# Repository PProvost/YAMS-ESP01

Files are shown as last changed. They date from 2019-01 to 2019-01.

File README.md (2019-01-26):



# YAMS-ESP01
Yet Another Motion Sensor - Uses an ESP01 and a cheap PIR motion sensor, sends activation events via MQTT,
optimized for very low power use. Runs on 3 AA batteries (I use Panasonic Eneloop NiMh cells).

## BOM

* ESP8266-01 Module
* HC-SR501 PIR Motion Detector
* MCP1700-3302E TO92 Voltage Regulator
* Resistors:
  - 220 ohm (x1)
  - 3.3K ohm (x1)
* Capacitors:
  - 1uF ceramic (x2)
  - 100nF ceramic (x1)
* Various pin headers, JST and molex connectors as you see fit
* Battery caddy (aim for > 4V but stay within the limits of the MCP1700-3302E)

## Implementation Notes:

* If you have a Puya-based ESP01 module, you may need to apply this patch to get SPIFFS to write correctly:
  https://github.com/letscontrolit/ESPEasy/blob/mega/patches/puya_v3.patch#L8
* You can force the WifiManager to reset its settings by writing the SPIFFS filesystem with a file called
  `/config.json` with the following contents: `{ "reset_settings": true }`. This file is included in the
  /data directory in this repo.

## Building the circuit

Credits: This circuit used in this design is based on the work described in [Benny de Leeuw's article][1].

IMPORTANT!: This is a 3.3V circuit. The HC-SR501 PIR sensor is 5V, so you either need to maintain two power
voltages or modify the PIR to run on 3.3V.

The circuit is designed to be battery powered, requiring between 3.7V and 6V due to the requirements
of the MCP1700 LDO. This requires some special with your PIR sensor. Most of the cheap ones you will
find expect 5V. See below for more information about modding your PIR sensor for 3V3.

Once I've built a few and ironed out the bugs, I will provide STLs for a case and a link to the PCB
on OSHPark.

Please refer to the schematic PDF and the other files in the schematic/ folder.

### Modding the HC-SR501 PIR Sensor

I wanted to reuse the VCC pin on the PIR sensor to make mounting easier, but also to power the PIR sensor
with the same 3.3VDC the ESP takes. For some of my sensors, I made the following modifications successfully:

* Removed the 3V3 voltage regulator
* Connected the cathode (output) side of the diode to the VOUT pad where the regulator had been connected
* Removed the 1k resistor between the controller IC and the signal pin and shorted the two pads.
* NOTE:This permanently changes the sensor to only take 3.3V, do not power it with 5V after removing the regulator.
  If you don't want to remove the regulator from your sensor, you can still power it with 3.3V following the guide [Modifying Cheap PIR Sensors][3], but you may still need to remove the 1k resistor. I've used this approach too.

## Credits & References

1. [Stable ESP01 Motion Sensor][1]
2. [ESP01 Pin Magic][2]
3. [Modifying Cheap PIR Sensors][3]

## TODO:

* Provide a better HASS discovery message
* Better case design
* Button/switch/jumper to make it stay awake (can help with network debugging; see also the DO_NOT_SLEEP define
  in main.cpp)
* Enable [OTA updating](http://esp8266.github.io/Arduino/versions/2.0.0/doc/ota_updates/ota_updates.html),
* Figure out a reset button so you can reset the configuration without flashing the SPIFFS filesystem
  particularly for updating the config.json file but also maybe the firmware.
* (Optional) front facing LED when motion detected
* (Idea) Photoresistor to prevent triggering unless light levels are low enough

[1]: https://medium.com/@leeuwte/stable-esp01-motion-sensor-for-mqtt-2d81c0b1e317
[2]: http://www.forward.com.au/pfod/ESP8266/GPIOpins/ESP8266_01_pin_magic.html
[3]: https://randomnerdtutorials.com/modifying-cheap-pir-motion-sensor-to-work-at-3-3v/

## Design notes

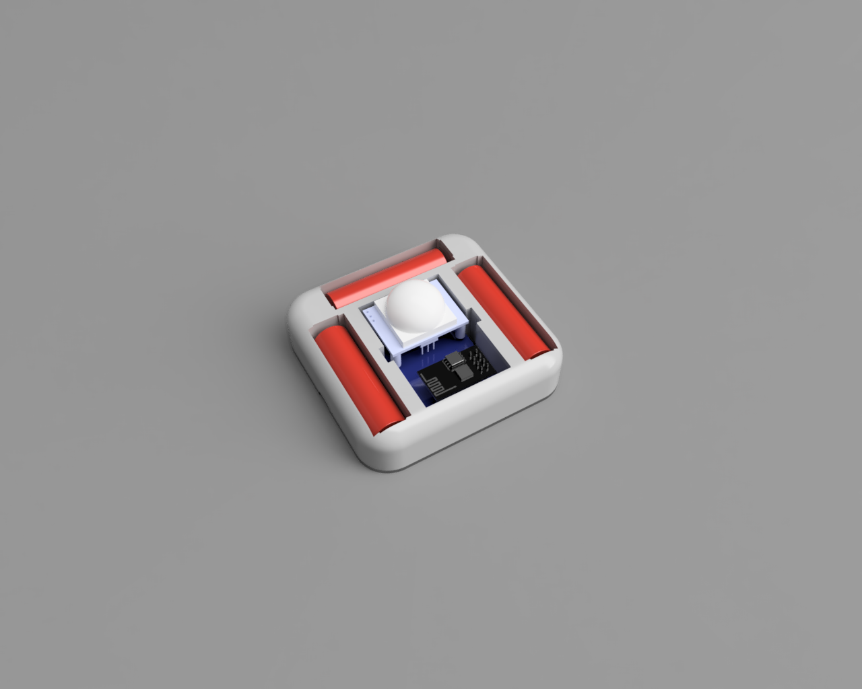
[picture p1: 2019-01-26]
stl/YAMS-Case-New-Everything-Top-Removed.png

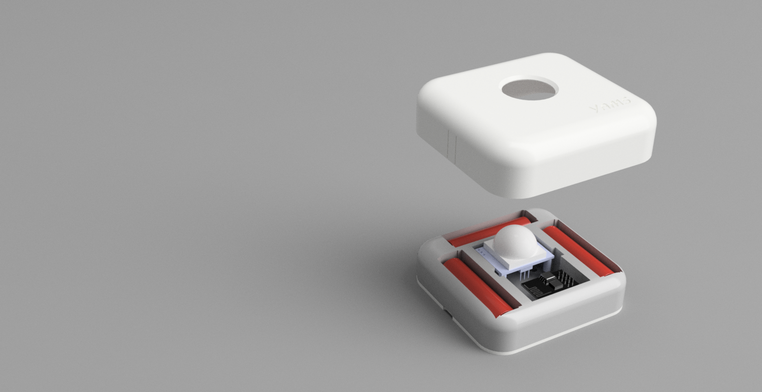
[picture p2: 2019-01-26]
stl/YAMS Round Exploded.png

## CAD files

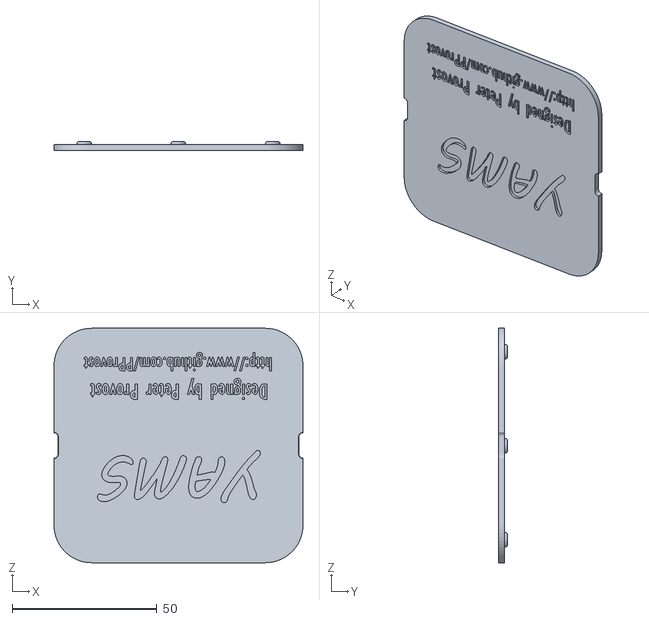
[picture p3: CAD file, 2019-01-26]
stl/Case - Inner Block Bottom Plate.stl
86.0 x 3.00 x 81.0

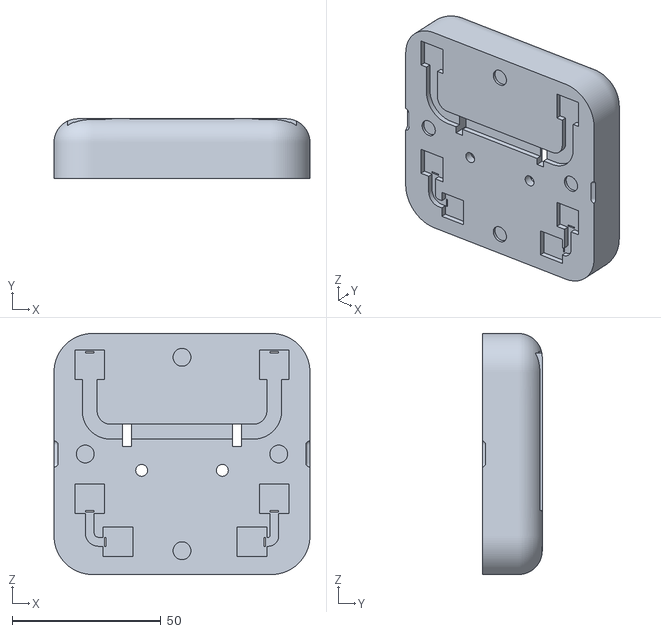
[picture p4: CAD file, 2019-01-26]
stl/Case - Inner Block.stl
86.0 x 20.0 x 81.0

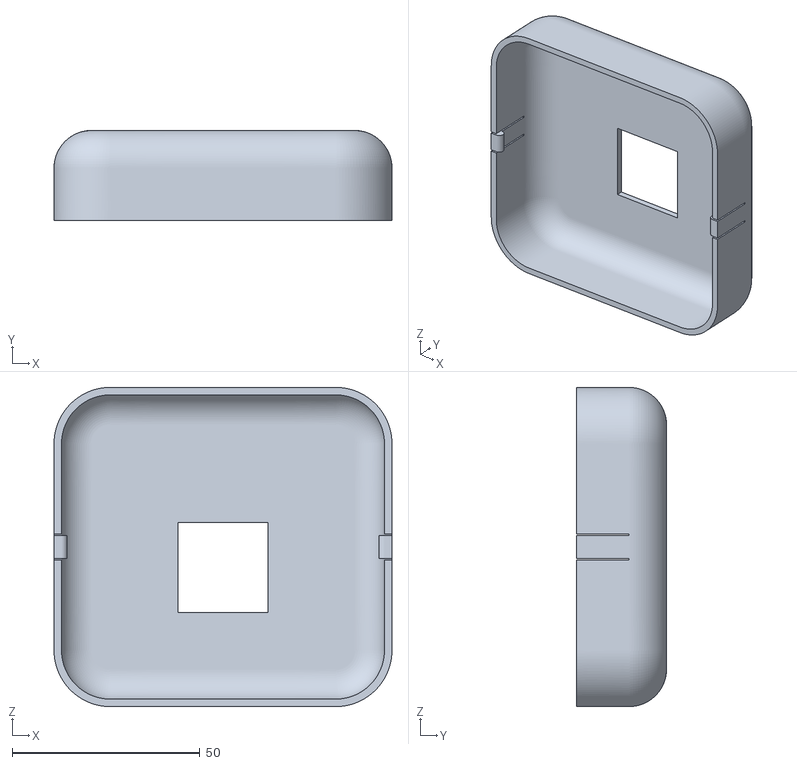
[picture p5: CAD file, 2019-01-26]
stl/Case - Outer Shell.stl
90.0 x 24.0 x 85.0

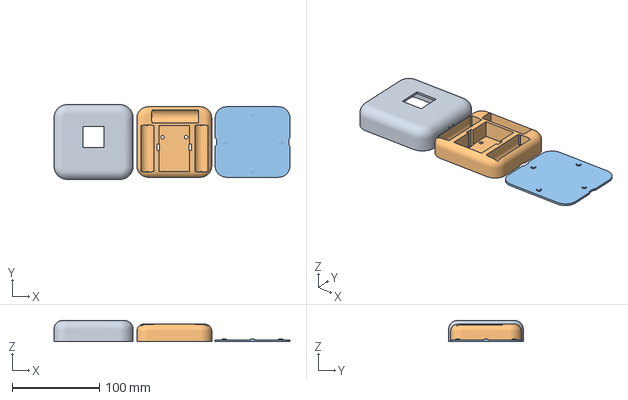
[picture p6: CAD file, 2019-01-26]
stl/YAMS-Case-New-Everything-PLA.curaproject.3mf
271.0 x 85.8 x 24.2 mm

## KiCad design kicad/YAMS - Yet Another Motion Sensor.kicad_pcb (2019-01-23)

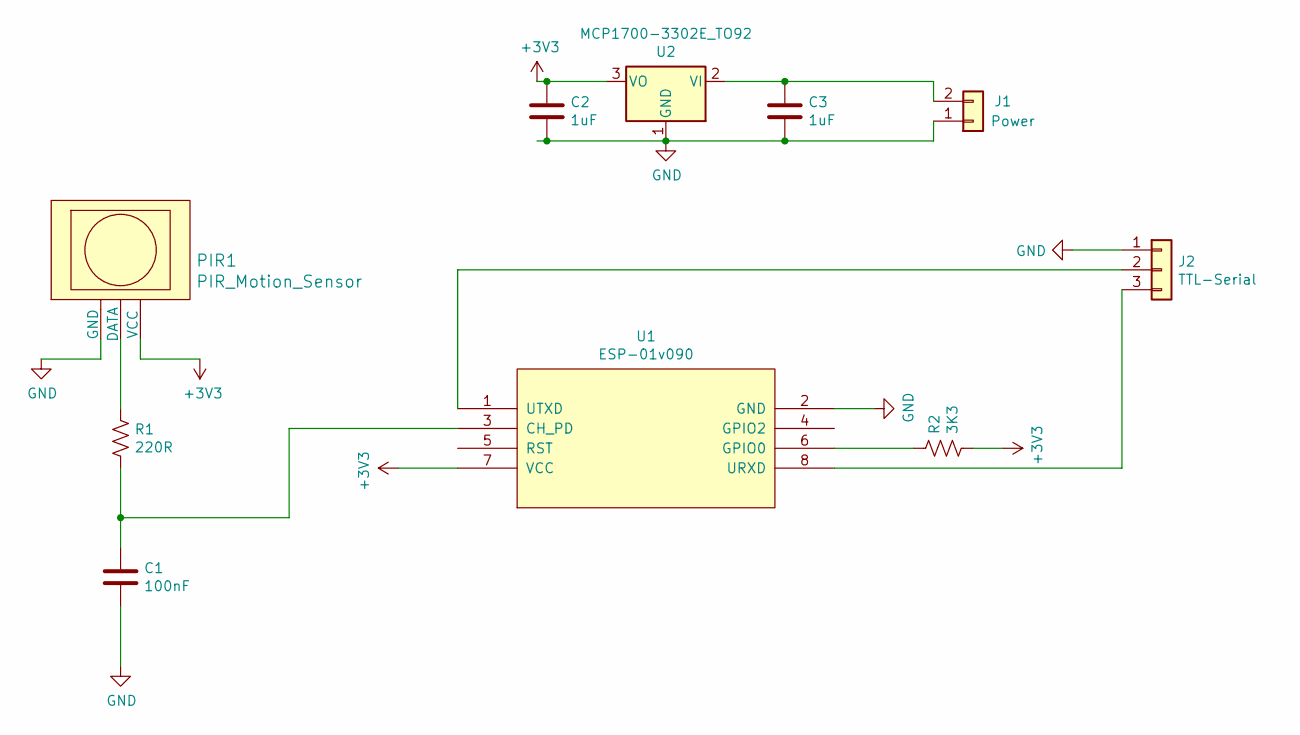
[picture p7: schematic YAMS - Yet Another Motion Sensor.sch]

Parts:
C1: 100nF; C_Disc_D3.8mm_W2.6mm_P2.50mm
C2, C3: 1uF; C_Disc_D3.8mm_W2.6mm_P2.50mm
J1: Power; JST_XH_B02B-XH-A_1x02_P2.50mm_Vertical
J2: TTL-Serial; PinHeader_1x03_P2.54mm_Vertical
PIR1: PIR_Motion_Sensor; PIR_Motion_Sensor_Horiz
R1: 220R; R_Axial_DIN0207_L6.3mm_D2.5mm_P7.62mm_Horizontal
R2: 3K3; R_Axial_DIN0207_L6.3mm_D2.5mm_P7.62mm_Horizontal
U1: ESP-01v090; ESP-01
U2: MCP1700-3302E_TO92; TO-92_Inline

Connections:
+3V3: C2.1, PIR1.3 (VCC), R2.2, U1.7 (VCC), U2.3 (VO)
GND: C1.2, C2.2, C3.2, J1.1, J2.1, PIR1.1 (GND), U1.2 (GND), U2.1 (GND)
unnamed: C1.1, R1.2, U1.3 (CH_PD)
unnamed: C3.1, J1.2, U2.2 (VI)
unnamed: J2.2, U1.1 (UTXD)
unnamed: J2.3, U1.8 (URXD)
unnamed: PIR1.2 (DATA), R1.1
unnamed: R2.1, U1.6 (GPIO0)

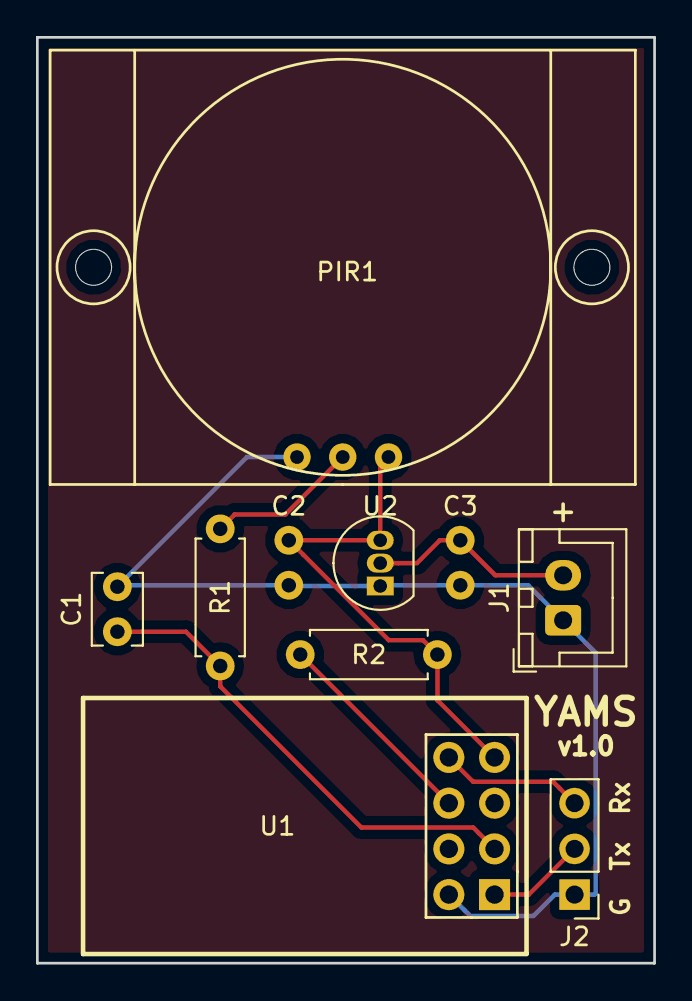
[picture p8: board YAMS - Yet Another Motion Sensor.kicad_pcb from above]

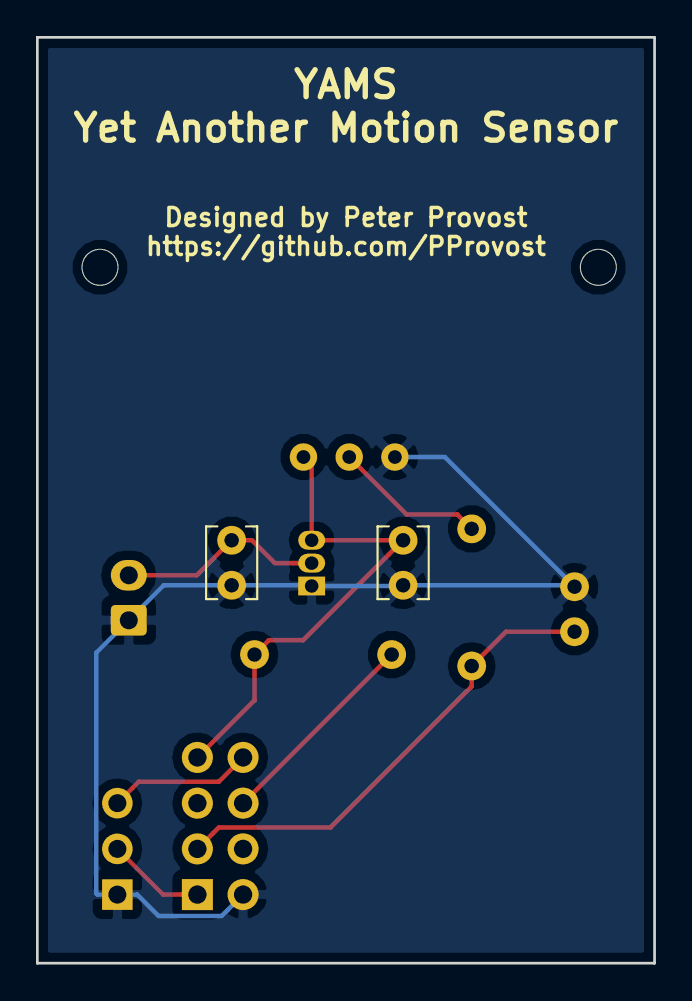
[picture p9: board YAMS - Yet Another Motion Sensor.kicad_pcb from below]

Board: 2 copper layers, 34.3 x 51.4 mm, 10 parts (2 on the bottom side), 8 nets.

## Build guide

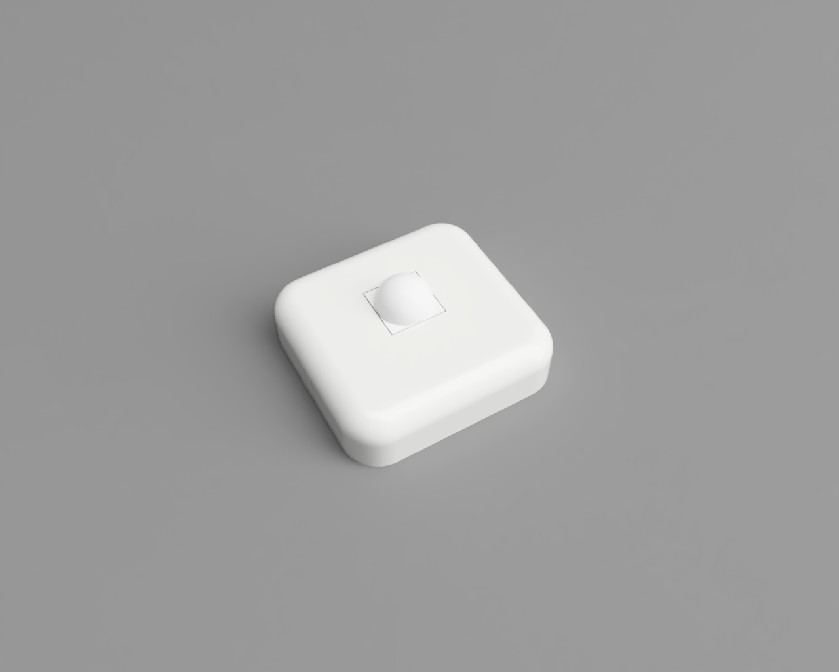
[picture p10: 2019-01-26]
stl/YAMS-Case-New-Everything-Assembled.png

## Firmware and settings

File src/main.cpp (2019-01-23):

#include <Arduino.h>
#include <ESP8266WiFi.h>
#include <PubSubClient.h>

#include "mqttConfig.h"
#include "wifi_helper.h"

// Change this for each device you create
const char *device_host_name = "esp8266-motion-1";

// Change the motion sensor topic as required for your configuration.
// Note that for HASS discovery to work, the structure is expected to be
// <discovery_prefix>/<component>/[<node_id>/]<object_id>
// I'm not using node_id, and the code below will append either "config" 
// (for discovery) or "state" as required.
// See https://www.home-assistant.io/docs/mqtt/discovery/ for more info.
const char *mqtt_topic_template = "esp8266/binary_sensor/DEVICE_HOST_NAME/";

// DEBUGGING: Uncomment to prevent deep sleep at the end of loop() and
// instead just delay for 5s. Useful for debugging or when you need to keep it
// awake. Do not leave this defined or your battery will die in days.
// #define DO_NOT_SLEEP

// This is the number of milliseconds between "on" state and "off" state.
// For simplicity, we do not wait for the PIR to register inactive.
#define INACTIVE_DELAY 2000

PubSubClient client;
MqttConfig config("/config.json");
WifiHelper wifiHelper;
WiFiClient wifiClient;

// Forward declarations
void ensure_mqtt_connected();
void sendHassDiscoveryMessage();

void setup()
{
  Serial.begin(115200);
  // delay(2000); // Make it easier to monitor from the start. Remove when done debugging.
  Serial.println();

  Serial.println("setup() starting");

  config.read();
  wifiHelper.setup_wifi(config);

  Serial.println("Opening MQTT connection...");
  if (!client.connected())
    config.connectMqtt(client, wifiClient);

  sendHassDiscoveryMessage();

  Serial.println("INFO: setup() complete; Wifi and MQTT connected");
}

void loop()
{
  Serial.println("loop(): current config:");
  config.dumpAll(Serial);
  Serial.println();

  String mqttTopic = mqtt_topic_template;
  mqttTopic.replace("DEVICE_HOST_NAME", device_host_name);
  mqttTopic.concat("state");

  // Send on
  Serial.println("- Sending active message");
  client.publish(mqttTopic.c_str(), "ON");
  client.loop();

  // Wait a bit
  delay(INACTIVE_DELAY);

  // Send off
  Serial.println("- Sending inactive message");
  client.publish(mqttTopic.c_str(), "OFF");
  client.loop();

  delay(100);
  Serial.println("Sleeping...");

#ifndef DO_NOT_SLEEP
  ESP.deepSleep(0);
#else
  delay(5000);
#endif
}

void sendHassDiscoveryMessage()
{
  Serial.println("- Sending HASS discovery message");

  String mqttTopic = mqtt_topic_template;
  mqttTopic.replace("DEVICE_HOST_NAME", device_host_name);
  mqttTopic.concat("config");

  String message = "{ \"name\": \"DEVICE_NAME\", \"device_class\": \"motion\" }";
  message.replace("DEVICE_NAME", device_host_name);
  client.publish(mqttTopic.c_str(), message.c_str());
  client.loop();
}

// NOTE: 
// If we want to subscribe to MQTT messages for commands or settings, this is the callback
// void callback(char* topic, byte* payload, unsigned int length) {
//   Serial.print("Message arrived [");
//   Serial.print(topic);
//   Serial.print("] ");
//   for (int i = 0; i < length; i++) {
//     Serial.print((char)payload[i]);
//   }
//   Serial.println();
//   // Switch on the LED if an 1 was received as first character
//   if ((char)payload[0] == '1') {
//     // digitalWrite(BUILTIN_LED, LOW);   // Turn the LED on (Note that LOW is the voltage level
//     // but actually the LED is on; this is because
//     // it is active low on the ESP-01)
//   } else {
//     // digitalWrite(BUILTIN_LED, HIGH);  // Turn the LED off by making the voltage HIGH
//   }
// }

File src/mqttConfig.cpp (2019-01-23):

#include "mqttConfig.h"

#include <ArduinoJson.h>
#include <FS.h>

bool _spiffsMounted;

bool MqttConfig::connectMqtt(PubSubClient &client, WiFiClient &wifiClient)
{
    // For some reason PubSubClient and WiFiManager don't behave nicely together
    // but after some digging, I discovered that doing my own DNS lookup of the
    // mqtt_server solves it. Clearly WiFiManager is somehow screwing up the internal
    // wifi settings.
    // See my comment here for updates: https://github.com/tzapu/WiFiManager/issues/724#issuecomment-456617855
    IPAddress ipAddr;
    if (WiFi.hostByName(get_mqttServer().c_str(), ipAddr) != 1)
    {
        Serial.println("ERROR: Unable to resolve host name!");
        return false;
    }
    else
        Serial.printf("INFO: Host name resolved successfuly - %s\n", ipAddr.toString().c_str());

    // Loop until we're reconnected
    // Will only try 20 times before giving up
    int counter = 0;
    while (!client.connected() && (counter++ < 20))
    {
        Serial.println("Attempting MQTT connection...");
        // Create a random client ID
        String clientId = "ESP8266Client-";
        clientId += String(random(0xffff), HEX);

        Serial.printf("  server: %s\n", get_mqttServer().c_str());
        Serial.printf("  username: %s\n", get_mqttUsername().c_str());
        Serial.printf("  password: %s\n", get_mqttPassword().c_str());

        // Attempt to connect
        client.setClient(wifiClient);
        client.setServer(ipAddr, 1883);
        if (client.connect(clientId.c_str(), get_mqttUsername().c_str(), get_mqttPassword().c_str()))
        {
            Serial.println("connected");
        }
        else
        {
            Serial.print("  failed, rc=");
            Serial.print(client.state());
            Serial.println("  try again in 5 seconds");
            // Wait 5 seconds before retrying
            delay(5000);
        }
    }

    return client.connected();
}

bool MqttConfig::read()
{
    if (!_spiffsMounted)
    {
        if (!SPIFFS.begin())
        {
            Serial.println("ERROR: failed to mount SPIFFS");
            return false;
        }
        else
            _spiffsMounted = true;
    }

    if (!SPIFFS.exists(_filepath))
    {
        Serial.printf("ERROR: file %s does not exist\n", _filepath.c_str());
        return false;
    }

    File f = SPIFFS.open(_filepath, "r");

    StaticJsonBuffer<JSON_DOC_BUFFER_SIZE> jsonBuffer;
    JsonObject &root = jsonBuffer.parse(f);

    Serial.printf("MqttConfig::read() loaded the following JSON from %s\n", _filepath.c_str());
    root.printTo(Serial);
    Serial.println();

    if (root.containsKey("reset_settings"))
        _resetSettings = true;

    _mqttServer = root["mqtt_server"].as<String>();
    _mqttUsername = root["mqtt_username"].as<String>();
    _mqttPassword = root["mqtt_password"].as<String>();

    return true;
}

bool MqttConfig::save()
{
    if (!_spiffsMounted)
    {
        if (!SPIFFS.begin())
        {
            Serial.println("ERROR: failed to mount SPIFFS");
            return false;
        }
        else
            _spiffsMounted = true;
    }

    if (!SPIFFS.exists(_filepath))
    {
        Serial.printf("WARNING: (warning) file %s does not exist and will be created\n", _filepath.c_str());
    }

    Serial.println("Writing JSON:");
    StaticJsonBuffer<JSON_DOC_BUFFER_SIZE> jsonBuffer;

    JsonObject &root = jsonBuffer.createObject();
    // Note: We do not write the reset key
    root["mqtt_server"] = _mqttServer;
    root["mqtt_username"] = _mqttUsername;
    root["mqtt_password"] = _mqttPassword;

    File f = SPIFFS.open(_filepath, "w");
    root.printTo(f);
    f.flush();
    f.close();

    return true;
}

void MqttConfig::dumpAll(Stream &stream)
{
    stream.println("MqttConfig:");
    stream.printf(" - _resetSettings: %s\n", (_resetSettings ? "true" : "false"));
    stream.printf(" - _mqttServer: %s\n", _mqttServer.c_str());
    stream.printf(" - _mqttUsername: %s\n", _mqttUsername.c_str());
    stream.printf(" - _mqttPassword: %s\n", _mqttPassword.c_str());
}

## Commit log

2019-01-15 Added KiCad files for circuit and PCB design
    [YAMS - Yet Another Motion Sensor.kicad_pcb, YAMS - Yet Another Motion Sensor.sch]
2019-01-15 Wrong case in include?
    [main.cpp]
2019-01-16 Argh. Why won't Travis pick up the include??
    [main.cpp]
2019-01-19 Updates to schematic and PCB
    [YAMS - Yet Another Motion Sensor.kicad_pcb, YAMS - Yet Another Motion Sensor.sch]
2019-01-19 Initial draft of a 3D printed case
    [Case Bottom.stl, Case Top and Bottom.curaproject.3mf, Case Top.stl]
2019-01-23 Updates to readme and few other little things.
    [YAMS - Yet Another Motion Sensor.kicad_pcb]
2019-01-26 Lots of updates to the case
    [Case - Inner Block Bottom Plate.stl, Case - Inner Block.stl, Case - Outer Shell.stl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]
